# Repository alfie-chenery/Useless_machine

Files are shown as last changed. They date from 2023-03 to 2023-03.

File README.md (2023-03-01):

This repo contains all the recovery files for the useless box.

The directory software/useless_machine contains the .ino file which can be
uploaded to the arduino nano, in the case the onboard file is damaged
or the EEPROM offset needs incrementing.
Help here:
https://www.arduino.cc/en/Guide/ArduinoNano

The directory prints contains all the .stl and .gcode files for pieces
3D printed.

Also included are files for the circuit diagram and box specifications.

Happy Birthday Dayana,
Love from Alfie ~x

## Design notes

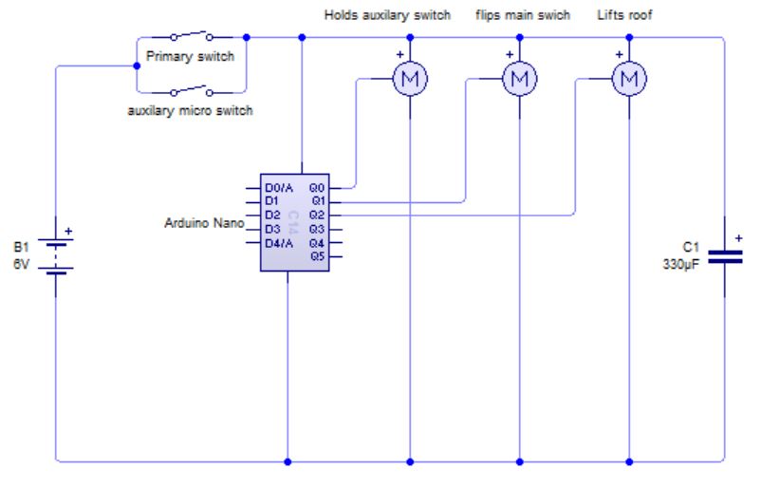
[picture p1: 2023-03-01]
hardware/circuit_diagram.JPG

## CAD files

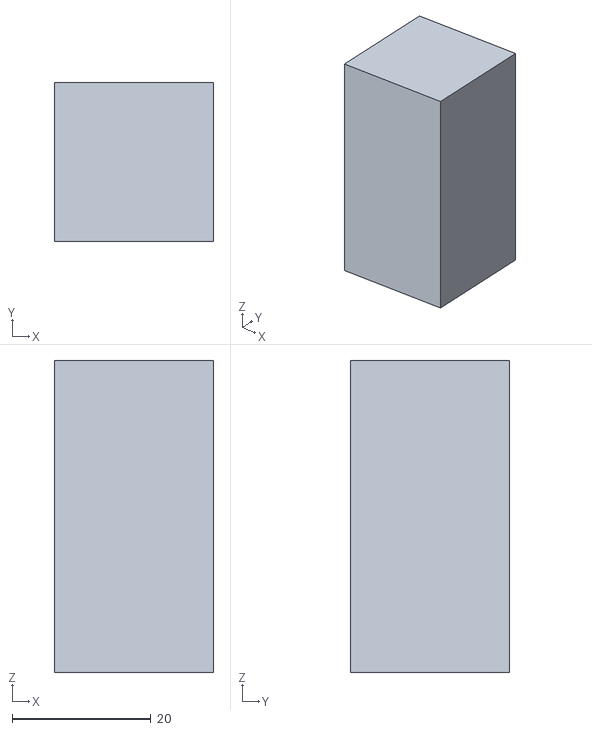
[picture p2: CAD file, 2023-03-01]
hardware/3d prints/main arm holder/main arm holder.stl
23.0 x 23.0 x 45.0

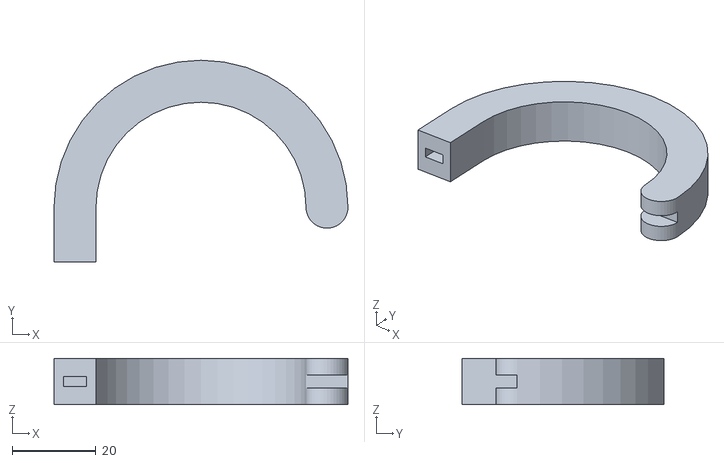
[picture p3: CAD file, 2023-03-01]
hardware/3d prints/main arm/main arm.stl
70.0 x 48.0 x 11.0

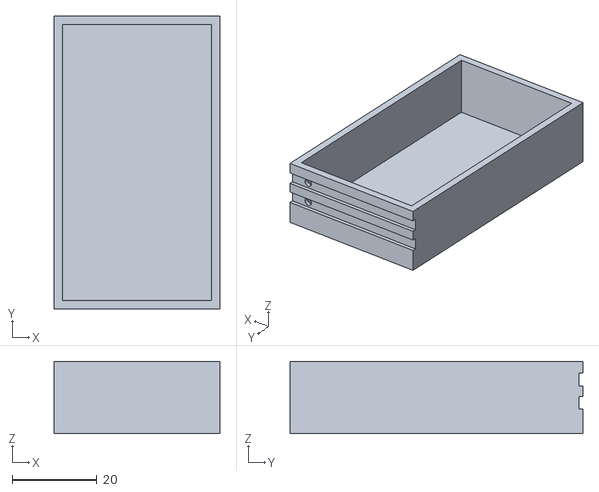
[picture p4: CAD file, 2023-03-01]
hardware/3d prints/battery holder/battery holder.stl
39.0 x 69.0 x 17.0

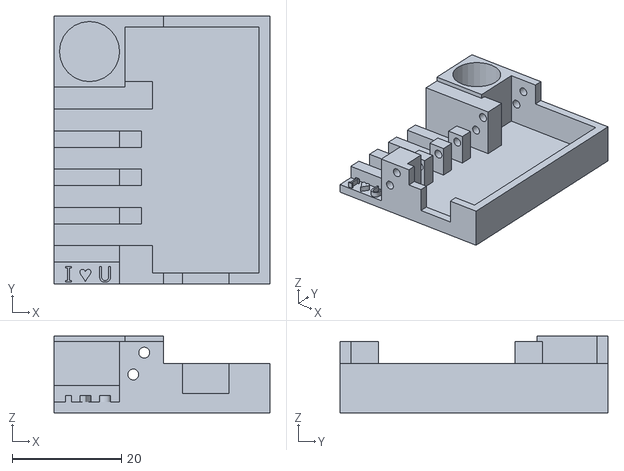
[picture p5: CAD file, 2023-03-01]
hardware/3d prints/chip holder/chip holder.stl
39.5 x 49.0 x 14.0

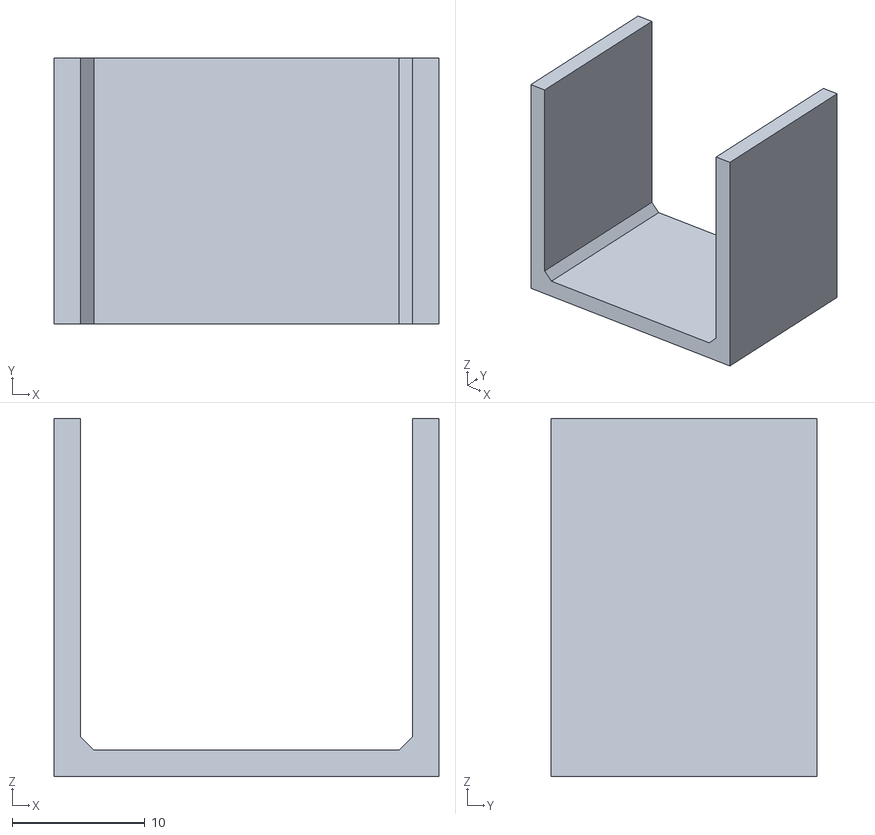
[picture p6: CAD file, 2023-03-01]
hardware/3d prints/microswitch cover/microswitch cover.stl
29.0 x 20.0 x 27.0

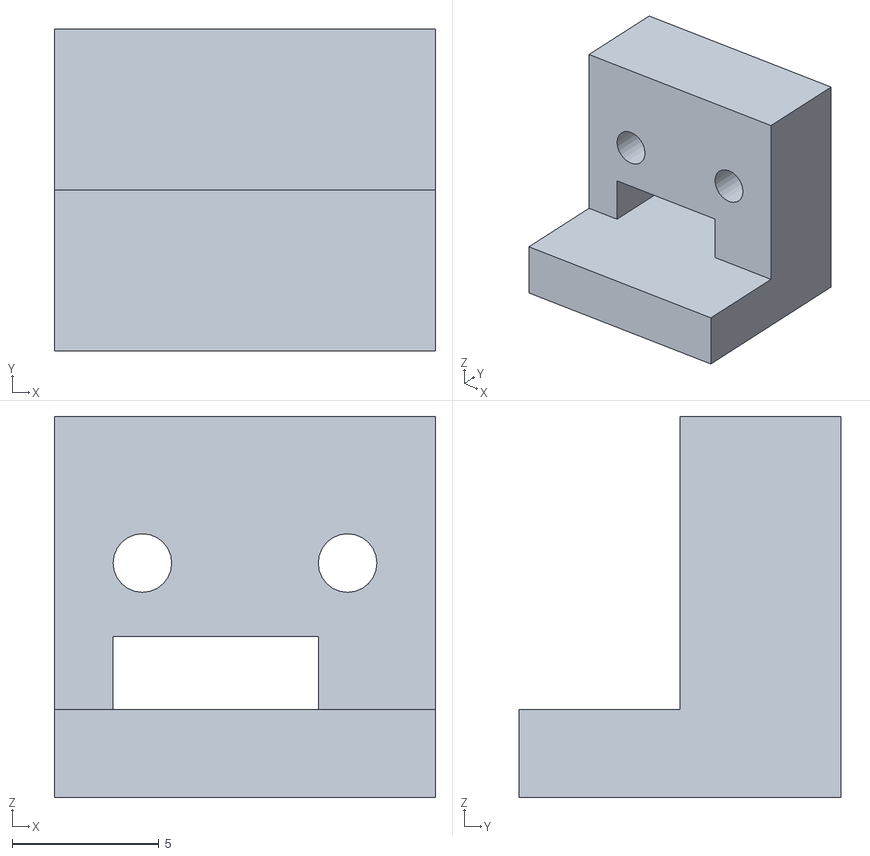
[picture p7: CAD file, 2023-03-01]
hardware/3d prints/microswitch holder/microswitch holder.stl
13.0 x 11.0 x 13.0

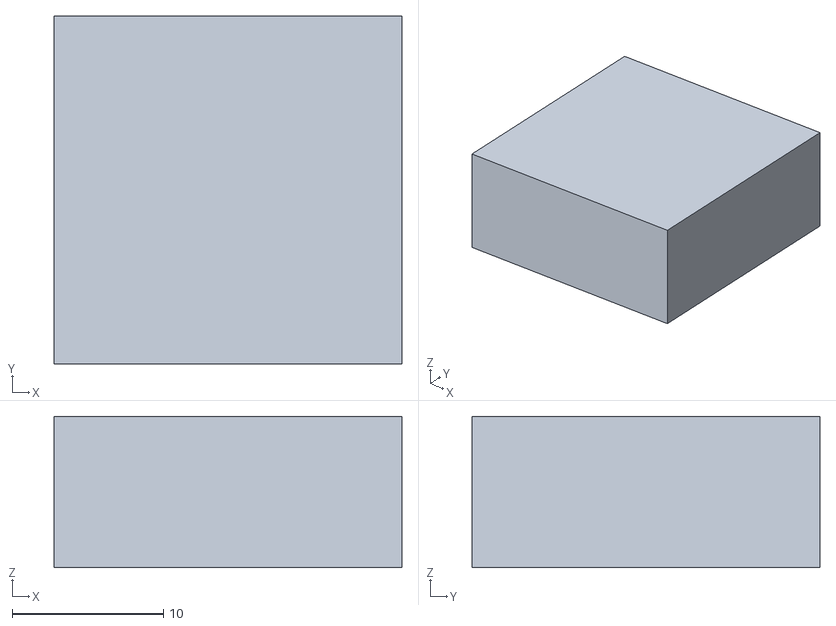
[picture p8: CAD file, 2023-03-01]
hardware/3d prints/microswitch servo spacer/microswitch servo spacer.stl
23.0 x 23.0 x 10.0

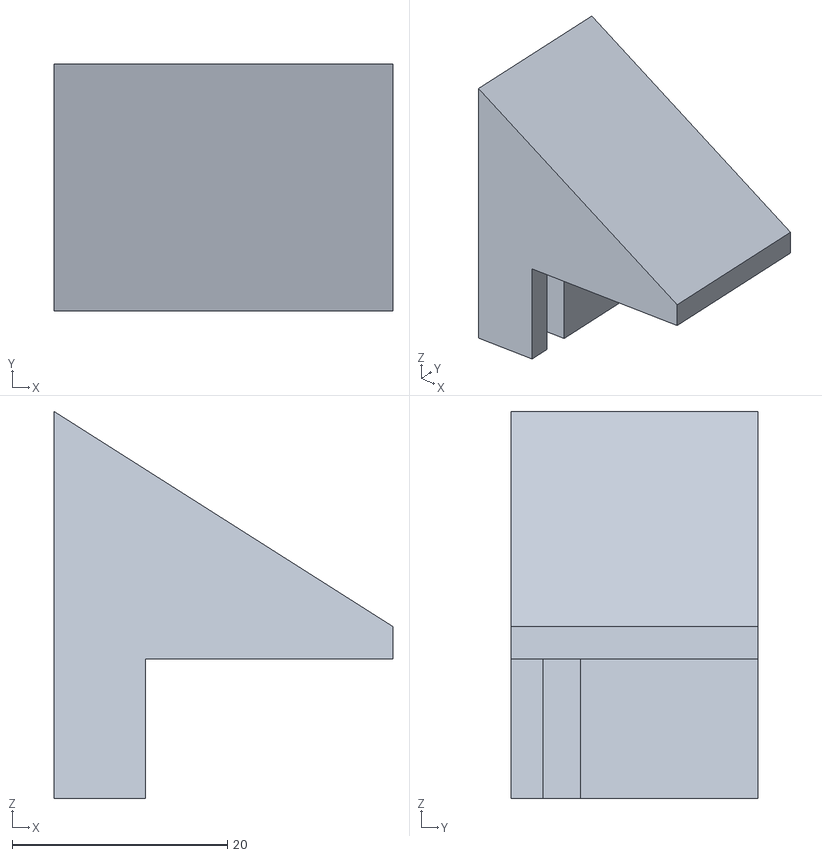
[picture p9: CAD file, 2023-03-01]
hardware/3d prints/roof arm holder/roof arm holder.stl
31.5 x 23.0 x 36.0

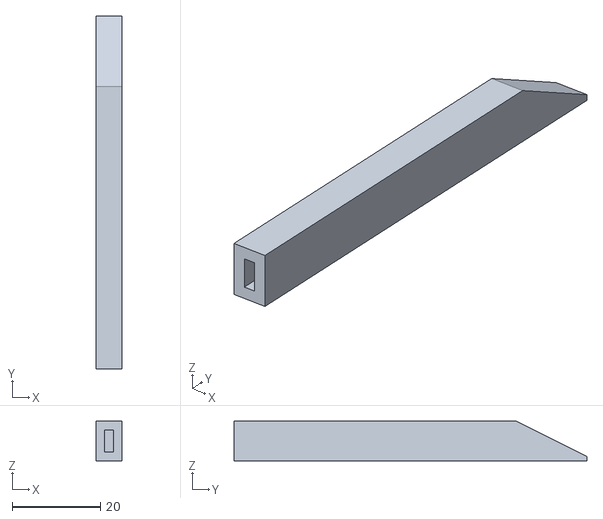
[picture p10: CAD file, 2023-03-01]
hardware/3d prints/roof arm/roof arm.stl
6.00 x 80.0 x 9.00

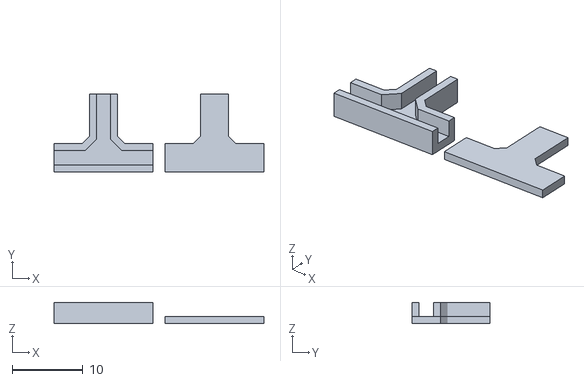
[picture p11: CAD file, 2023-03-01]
hardware/3d prints/solder T connector/solder T connector.stl
29.7 x 11.0 x 3.00

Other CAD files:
hardware/3d prints/battery holder/battery holder.skp
hardware/3d prints/chip holder/chip holder.skp
hardware/3d prints/main arm holder/main arm holder.skp
hardware/3d prints/main arm/main arm.skp
hardware/3d prints/microswitch cover/microswitch cover.skp
hardware/3d prints/microswitch holder/microswitch holder.skp
hardware/3d prints/microswitch servo spacer/microswitch servo spacer.skp
hardware/3d prints/roof arm holder/roof arm holder.skp
hardware/3d prints/roof arm/roof arm.skp
hardware/3d prints/solder T connector/solder T connector.skp
hardware/box specifications.skp

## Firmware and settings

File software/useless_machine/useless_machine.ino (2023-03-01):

//----------definitions----------
//install modules
#include <Servo.h>
#include <EEPROM.h>

//define global objects & variables
Servo aux_power;
Servo roof_arm;
Servo main_arm;
int NUM_OF_MODES = 14;
int UNUSED_PIN = 8;
int EEPROM_ADDRESS = 3; //manually += 1 if EEPROM cells die
/*
 * EEPROM has a rated lifespan of 10000 write cycles per individual cell.
 * As explained in chooseMode() each cell is written on average every 4th execution
 * So after 40000 executions the EEPROM_ADDRESS needs incrementing.
 * If this value reaches 128, the whole EEPROM is dead and chip needs replacing
 */

//define function headers with optional parameter
  //if function is called without optional wait parameter then wait will default to 0
void set_aux_power(int pos, int wait=0);
void set_roof_arm(int pos, int wait=0);
void set_main_arm(int pos, int wait=0);
  
//----------main code----------
void setup() {

  //seed random generator and choose mode
  int mode = chooseMode();
  Serial.println(mode);

    
  //attatch servos to pwm pins
  aux_power.attach(6);
  roof_arm.attach(11);
  main_arm.attach(10);

  homeServos();
  set_aux_power(100,500); //presses microswitch
                                              
  runProcedure(mode); //transition code written in function to keep setup readable
                      //main_arm and roof_arm should be homed inside of runProcedure

  homeServos(); //releases microswitch, cuts power

  /*
   * power to the arduino will likely be cut before the servo reaches its full right position
   * this is not an issue as it will be homed to centre on next startup
   * for the same reason, the below code will only run when power cannot be cut, such as
   * when being powered from USB during recoding.
  */

  delay(1000);
  aux_power.detach();           //detatch servos from pins
  roof_arm.detach();
  main_arm.detach();
  pinMode(LED_BUILTIN, OUTPUT); //initialise onboard LED for output, to be used in loop
  
}

void loop() {
  /*  
   *  code below flashes the onboard LED to signal normal execution should have ended
  */
  digitalWrite(LED_BUILTIN, HIGH);
  delay(1000);
  digitalWrite(LED_BUILTIN, LOW);
  delay(1000);
}


/*
 * servo set functions take parameter as integer from 0 to 100
 * servo limits are defined such that min is home position and max
 * is fully extended to perorm transitions
 * As such it may be that min > max if servo is mounted in reverse
 * 
 * set_main_arm(80) is touching the switch but not flipping it to have 
 * enough force to flip switch must go from 80 (or lower) straight to 100
 */
void set_aux_power(int pos, int wait){
  //define servo limits
  int Min = 1650;  //released
  int Max = 1450;  //pressed
  int sig = map(pos, 0, 100, Min, Max);
  aux_power.writeMicroseconds(sig);
  delay(wait);
}

void set_roof_arm(int pos, int wait){
  //define servo limits
  int Min = 1500;  //closed
  int Max = 950;  //open
  int sig = map(pos, 0, 100, Min, Max);
  roof_arm.writeMicroseconds(sig);
  delay(wait);
}

void set_main_arm(int pos, int wait){
  //define servo limits
  int Min = 2300;  //retracted
  int Max = 850;  //extended
  int sig = map(pos, 0, 100, Min, Max);
  main_arm.writeMicroseconds(sig);
  delay(wait);
}

void homeServos(){
  set_main_arm(0);
  set_roof_arm(0);
  set_aux_power(0);
}


void runProcedure(int mode){
  switch(mode){
    case 0: //immediate switch
      set_roof_arm(100, 250);
      set_main_arm(100, 750);
      set_main_arm(0, 750);
      set_roof_arm(0, 100);
      break;

    case 1: //pause before switching
      set_roof_arm(100, 250);
      set_main_arm(90, 2000);
      set_main_arm(100, 500);
      set_main_arm(0, 500);
      set_roof_arm(0, 100);
      break;

    case 2: //bang roof
      set_roof_arm(100,1000);
      set_roof_arm(0, 250);
      for(int i=0; i<3; i++){
        set_roof_arm(80, 250);
        set_roof_arm(0, 250);
      }
      set_roof_arm(100,500);
      set_main_arm(100,1000);
      set_main_arm(0,500);
      set_roof_arm(0,500);
      break;

    case 3: //slowly aproach switch, fast retraction
      for(int i=0; i<100; i++){
        set_roof_arm(i, 10);
      }
      delay(1000);
      for(int i=0; i<85; i++){
        set_main_arm(i, 10);
      }
      delay(2500);
      set_main_arm(100,150);
      set_main_arm(0,250);
      set_roof_arm(0,100);
      break;

    case 4: //slowly aproach switch, slow retraction
      for(int i=0; i<=100; i++){
        set_roof_arm(i, 10);
      }
      delay(1000);
      for(int i=0; i<=85; i++){
        set_main_arm(i, 10);
      }
      delay(2500);
      set_main_arm(100,150);
      delay(2000);
      for(int i=100; i>=0; i--){
        set_main_arm(i, 10);
      }
      delay(1000);
      for(int i=100; i>=0; i--){
        set_roof_arm(i, 10);
      }
      break;

    case 5: //repeatedly get closer to switch
      set_roof_arm(100, 1000);
      for(int i=0; i<5; i++){
        set_main_arm(60 + 5*i, 300); 
        set_main_arm(0, 500);
      }
      set_main_arm(100, 500);
      set_main_arm(0, 1000);
      set_roof_arm(0, 100);
      break;

    case 6: //shake arm after switch
      set_roof_arm(100, 1000);
      set_main_arm(100, 3000);
      for(int i=0; i<4; i++){
        set_main_arm(55, 100);
        set_main_arm(95, 100);
      }
      delay(500);
      set_main_arm(0, 300);
      set_roof_arm(0, 100);
      break;

    case 7: //look back after switching
      set_roof_arm(100, 250);
      set_main_arm(100, 1000);
      set_main_arm(0, 1000);
      set_roof_arm(0, 2000);
      set_roof_arm(100, 1500);
      set_roof_arm(0, 100);
      break;

    case 8: //peak before switching
      set_roof_arm(50, 1000);
      set_roof_arm(0, 2000);
      set_roof_arm(100, 150);
      set_main_arm(100, 350);
      set_main_arm(0, 250);
      set_roof_arm(0, 100);
      break;

    case 9: //trap arm in roof
      set_roof_arm(100, 250);
      set_main_arm(100, 1000);
      set_roof_arm(0, 500);
      set_roof_arm(100, 250);
      set_main_arm(0, 500);
      set_roof_arm(0, 100);
      break;

    case 10: //hold switch
      set_roof_arm(100, 1000);
      set_main_arm(100, 4500);
      set_main_arm(0, 500);
      set_roof_arm(0, 100);
      break;

    case 11: //speedrun the switch
      set_roof_arm(100, 150);
      set_main_arm(100, 350);
      set_main_arm(0, 2000);
      set_roof_arm(0, 100);
      break;

    case 12: //keep checking switch
      set_roof_arm(100, 200);
      set_main_arm(100, 500);
      for(int i=100; i>=95; i--){
        set_main_arm(i, 20);
      }

      for(int k=3; k>=0; k--){
        if(k != 3){
          set_main_arm(95, 300);
        }
        for(int i=95; i>=20*k; i--){
          set_main_arm(i, 20);
        }
      }

      set_main_arm(0,500);
      for(int i=100; i>=0; i--){
        set_roof_arm(i, 10);
      }
      break;
      

    case 13: //miss switch first time
      set_roof_arm(100, 250);
      set_main_arm(90, 750);
      set_main_arm(0, 750);
      set_roof_arm(0, 1500);
      set_roof_arm(100, 750);
      set_main_arm(100, 500);
      set_main_arm(0, 750);
      set_roof_arm(0, 100);
      break;
  }
}

int chooseMode(){
   
  int seed = analogRead(UNUSED_PIN); //seed random number generator with noise of unused pin
  randomSeed(seed);

  Serial.begin(9600);
   
  int lastRuns[4];
  for(int i=0; i<4; i++){
    lastRuns[i] = EEPROM.read(EEPROM_ADDRESS * 8 + i);
    Serial.print(lastRuns[i]);Serial.print(" ");
  }
  Serial.println("");
   
  int indexFlags[4];
  for(int i=0; i<4; i++){
    indexFlags[i] = EEPROM.read(EEPROM_ADDRESS * 8 + 4 + i);
    Serial.print(indexFlags[i]);Serial.print(" ");
  }
  Serial.println("");
  
  int choice = lastRuns[0]; //force at least one iteration
  while (choice == lastRuns[0] || choice == lastRuns[1] || choice == lastRuns[2] || choice == lastRuns[3]){
    choice = random(0,NUM_OF_MODES);
  }

  //use indexFlags to work out which cell to write the new value to
  int val = indexFlags[0];
  int i=0;
  while(indexFlags[i] == val){
    i++;
    if(i == 4){
      i=0;
      val = 1-val; //swap 0->1, 1->0
      break;
    }
  }
  //i now stores the index of the head of the list
  //val now stores 1 - old value of indexFlags[i]
  // ie the value index i should be set to now the list is updated
  
  EEPROM.write(EEPROM_ADDRESS * 8 + i, choice);
  EEPROM.write(EEPROM_ADDRESS * 8 + 4 + i, val); 
  
  return choice;
}

/*
 * EEPROM uses a more complicated method to be more efficient. We store the codes of the last 4
 * chosen modes and want to avoid picking these again. However when we pick a new one we want to
 * add this to the list in EEPROM and evict the oldest of the 4 currently in EEPROM.
 * Keeping the list in order and shifting all codes along causes 4 writes per execution so is
 * ineficient given EEPROM life expectancy. A single cell to track the head of the list would
 * need writing every execution while the actual bytes would be written every 4 executions (average)
 * so cells dying at different times would create very complex controlling code.
 * The solution used is to have 4 shadow bytes which are set to 0 or 1. The configuration of these
 * values can be used to deterine the head of the list.
 * 
 * The head of the list is the byte corresponding to the first shadow byte which is not equal to
 * shadow byte 0. If all shadow bytes are the same, then shadow byte 0 is the head of the list.
 * 
 * The list is stored in 8 consecutive bytes of EEPROM. The first 4 bytes store the list data
 * The next 4 bytes store the corresponding shadow bytes. EEPROM[i+4] is the shadow byte to EEPROM[i].
 * The offset of the list in EEPROM can be incremented when cells die after 40000 executions.
 * 
 * EXAMPLE RUNTHROUGH
 * [0,1,2,3] [0,0,0,0] From the start configuration all shadow bytes are 0, so the head is at 0
 * When we update index 0 with the chosen mode we set its shadow byte to 1 to mark it has been recently changed
 * [6,1,2,3] [1,0,0,0]
 * Now we see a 1 as the first shadow bit, so find the first occurance with a 0 shadow bit, and this is the head
 * [6,7,2,3] [1,1,0,0]
 * this continues
 * [6,7,8,3] [1,1,1,0]
 * [6,7,8,9] [1,1,1,1]
 * Now when checking for a 0 shadow bit there are none. Therefore we start again from the 0th cell, but this time
 * reset shadow bits to 0 to mark instead.
 * [4,7,8,9] [0,1,1,1]
 * Now we see the first shadow bit is 0 and so the first 1 occurance is the head of the list
 * [4,2,8,9] [0,0,1,1]
 * [4,2,0,9] [0,0,0,1]
 * [4,2,0,3] [0,0,0,0] ...
 * 
 * This method halves the capacity of EEPROM from 1024 bytes to 512 as each byte also uses a shadow byte
 * However, each individual cell is only written to once in every 4 executions (along with its shadow byte)
 * Therefore the code can survive 40000 executions before the EEPROM addresses need incrementing.
 * So overall we have doubled the lifespan of the chip by quadrupling efficiency and only having capacity.
 * If we stored more than the last 4 modes the efficiency would increase further.
 */

/*
 * Old method which does not use EEPROM
 * Uses multiple reads of noise pin to try to decrease the chance of 2 consecutive executions
 * picking the same mode. There is no formal proof this method helps t reduce runs, although
 * by inspection it seems to. However is inferior to the guarenteed effectiveness of the EEPROM
 * method. This method's only advantage is that it can work on chips with dead EEPROM.
 * 
 * 
int chooseMode(){
     //seed pseudo random number generator. Just using analogRead was producing runs
     //this method makes the value used as seed less likely to be the same as the 
     //last runthrough
     
    int seed = 0;
    for(int i=0; i<10; i++){
      int read = analogRead(UNUSED_PIN);
      seed += i * read;
      delay(50);
      //configure wait time, reducing the time means reads are closer together and more likely
      // to read the same noise value. Increasing the time means the box does nothing for longer
      // when it is first turned on while it chooses a seed value.
    }
    Serial.println(seed);
    randomSeed(seed);

    int mode = random(0,NUM_OF_MODES);   //generate random number in range 0 to number of modes
                                     //random is bound exclusive so numOfModes is total modes including mode 0
    return mode;
}
*/

//----------functions for testing----------
void printEEPROM(){
  Serial.begin(9600);
  
  for(int j=0; j<128; j++){
    Serial.print(j*8);
    Serial.print(": ");
    for(int i=0; i<8; i++){
      Serial.print(EEPROM.read(i + j*8), HEX);
      Serial.print(" ");
    }
    Serial.println("");
  }
  Serial.println("");
}

void resetEEPROM(){
  for(int i=0; i<4; i++){
    EEPROM.write(EEPROM_ADDRESS * 8 + i, i);
  }
  for(int i=0; i<4; i++){
    EEPROM.write(EEPROM_ADDRESS * 8 + 4 + i, 0);
  }
}
